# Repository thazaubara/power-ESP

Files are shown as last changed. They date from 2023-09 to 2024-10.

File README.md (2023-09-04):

# power-ESP
Simple ESP microcontroller that publishes power consumption to local MQTT. Includes 3D printed case. 

# MQTT NodeMCU

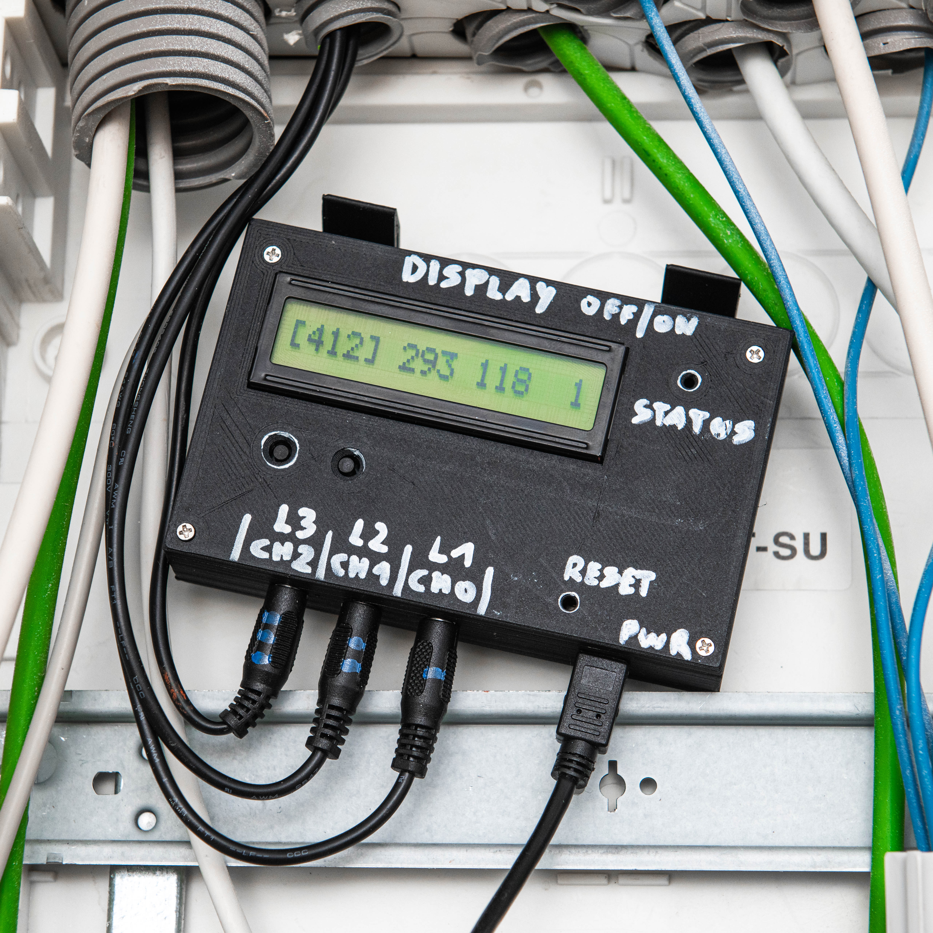
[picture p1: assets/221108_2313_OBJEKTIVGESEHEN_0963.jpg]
221108_2313_OBJEKTIVGESEHEN_0963


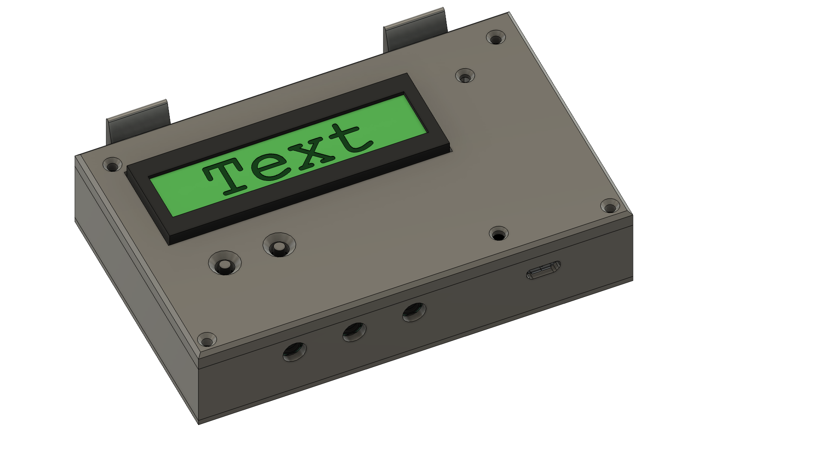
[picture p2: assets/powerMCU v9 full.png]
powerMCU v9 full


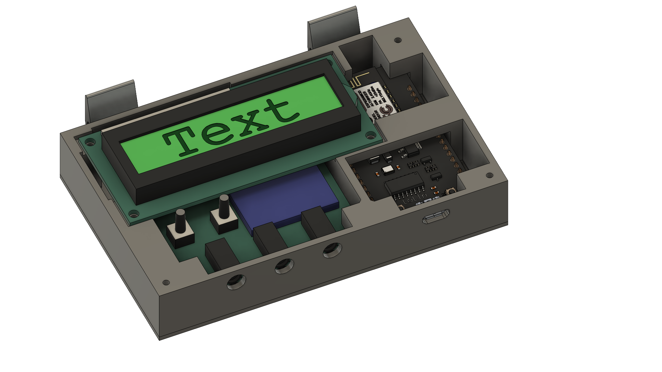
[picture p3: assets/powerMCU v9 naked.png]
powerMCU v9 naked


# NodeMCU

- Großes Board V3, 

- ESP8266, 

- CH340G USB-Serial

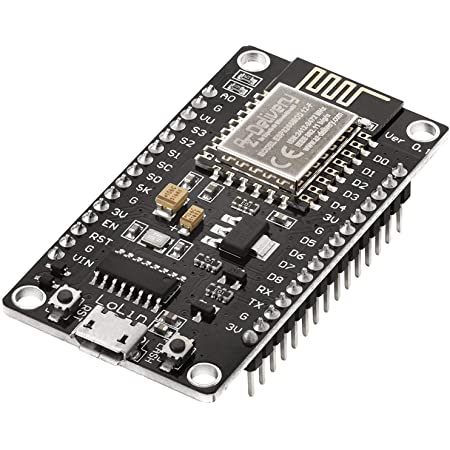
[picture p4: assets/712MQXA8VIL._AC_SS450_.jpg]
712MQXA8VIL._AC_SS450_
  

  NodeMCU Pinout Reference | Microcontroller Tutorials

# Software

- Arduino (Pro) IDE 2.0
- ESP Boards in Board Manager ([Tutorial](https://randomnerdtutorials.com/installing-esp8266-nodemcu-arduino-ide-2-0/))
- Braucht keine extra Treiber für USB-Serial @ M1 Macbook. Blinky läuft super.

# Projektspezfisch

- PubSubClient Library von Nick O'Leary ([Link](https://pubsubclient.knolleary.net)), in dem Library Manager von Arduino

# PowerMCU

## Features

- [ ] Display mit aktuellen Werten
- [ ] Cooles Case

## ToDo

Base Value reset (TARA)

Base Value im eeprom speichern

## Log

Vergleich [MCC118 RPI Hat](https://www.mccdaq.com/DAQ-HAT/MCC-118.aspx), [ADS1115](https://learn.adafruit.com/adafruit-4-channel-adc-breakouts/overview)
RPI Hat: 12 Bit, 8 CH, 100ks/s
ADS1115: 16 Bit, 4 CH, 860s/s

**[I2C Scanner](https://playground.arduino.cc/Main/sourceblock_1/index.txt?action=sourceblock&num=1) laufen gelassen**

Display: 0x27
ACD: 0x48

Display läuft, aber nur 8 zeichen von 16 (1 Zeile, mit I2C Board)
Vershiedene Modi:

- setup 8/2, cursor L0 L1
  nichts
- setup 16/1, cursor L0x16
  nur ersten 8 ch

Oke nach langem suchen und nichts finden, einfach display auf 5V (VUSB) angeschlossen, dann stimmt das
setup 16/2, L0x8, L1x8
ENDLICH

```c
LiquidCrystal_I2C lcd(0x27, 8, 2); // I2C address 0x27, 8 column and 2 rows
void printlcd(String s){
    lcd.setCursor(0,0);
    lcd.print(s.substring(0,8));
    lcd.setCursor(0,1);
    lcd.print(s.substring(8,16));
}
```

**Display funktioniert endlich.**

Upload Speed geiler machen. Wenn errors auftreten, hier ändern.

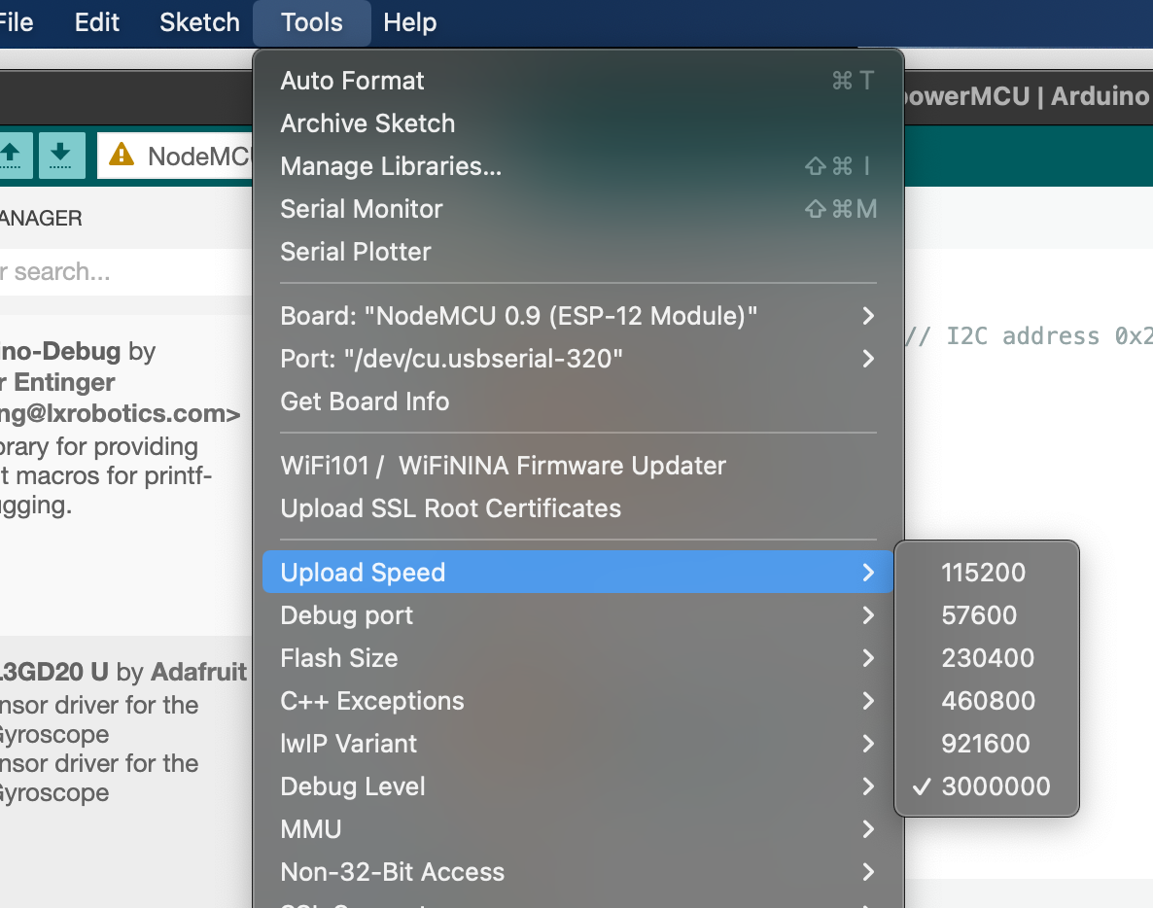
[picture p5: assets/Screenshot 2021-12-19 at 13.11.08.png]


ADC Sensor Basics mit der [Adafruit Library](https://learn.adafruit.com/adafruit-4-channel-adc-breakouts/arduino-code)

Berechnung der Spannung aus den Werten: einfache MAP Funktion

**Adafrut lib setzt ein delay** rein. limit 100 Samples pro sek. Andere Lib verwenden.

https://thecavepearlproject.org/2020/05/21/using-the-ads1115-in-continuous-mode-for-burst-sampling/

Lib geladen, installiert [Test sketch](https://github.com/terryjmyers/ADS1115-Lite/blob/master/examples/ADS1115_lite/ADS1115_lite.ino) rennt

Jetzt den Burst Mode: läuft auch

Test mit Klemme: Ikea 7W Lampe aufgebaut, kommt nichts an.
Stromzange sagt 0.05A wenns läuft. Auf 220V sind das 11 W

Das will ich auf der Klemme haben. Und am Oszi.

Alles rauscht extrem, ich bekomm kaum ein signal raus. ICh sollt einfach werte samplen über ne sekunde und dann berechnen, scheiß doch drauf. is keine Wissenschaft, sollte nur halbwegs passen.

Hier [einfaches Tutorial](https://www.poweruc.pl/blogs/news/non-invasive-sensor-yhdc-sct013-000-ct-used-with-arduino-sct-013) mit den selben sensoren. Trotzdem bessere lib nehmen statt adafruit.

Glühbirne reicht net. ich brauch mehr last. Habe den Föhn genommen

Glühbirne ~7W. Extrem viel rauschen. War ne LED, vielleicht liegts daran?

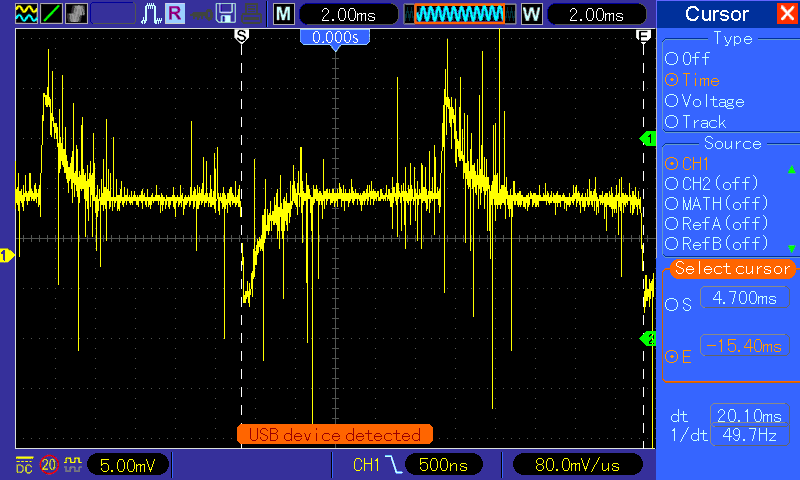
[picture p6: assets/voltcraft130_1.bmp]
voltcraft130_1


Föhn auf Vollgas ~2200W. Damit kann man arbeiten 😜 

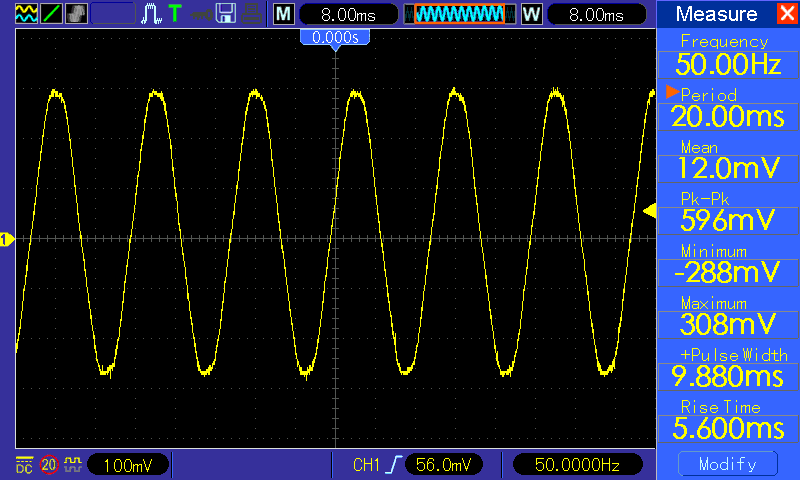
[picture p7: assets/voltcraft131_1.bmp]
voltcraft131_1


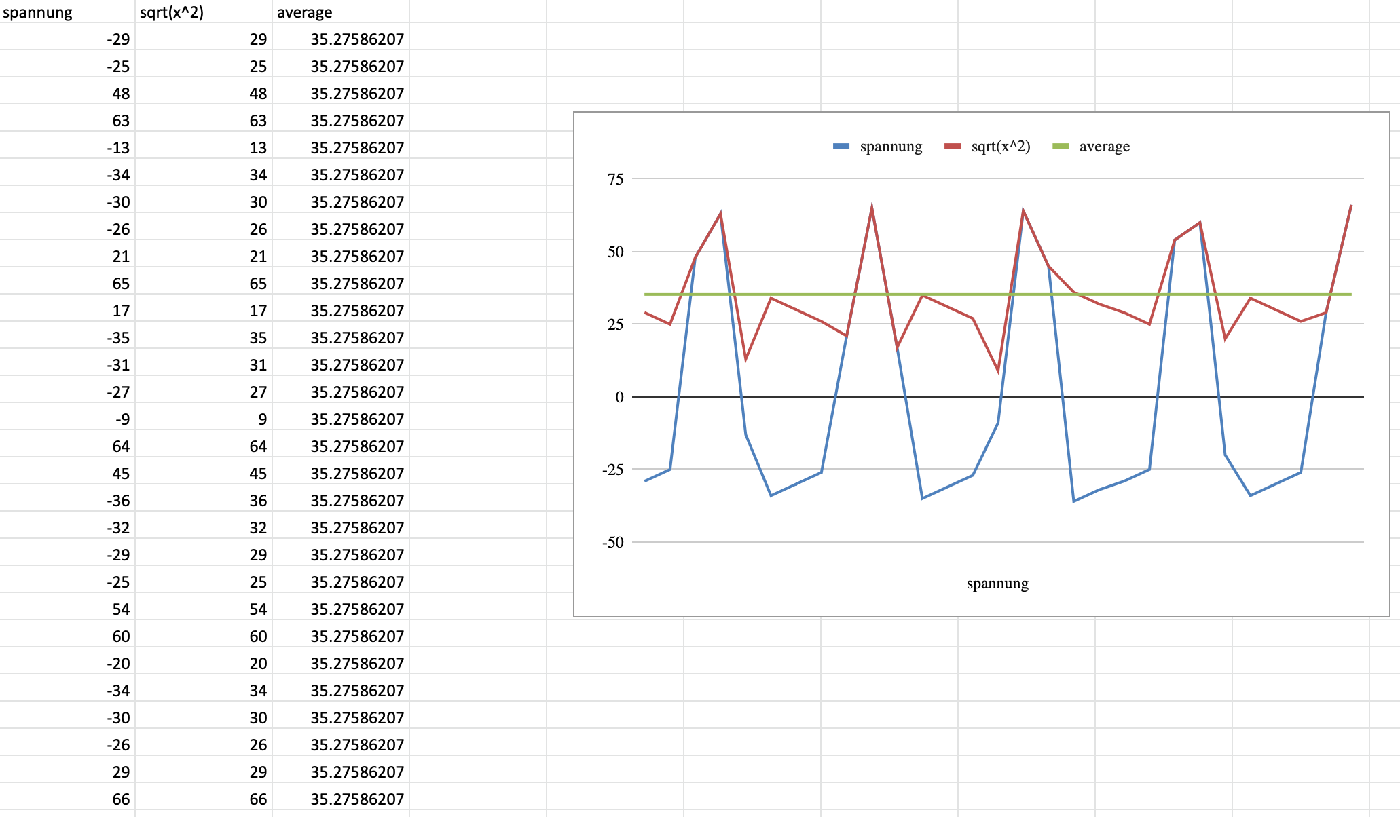
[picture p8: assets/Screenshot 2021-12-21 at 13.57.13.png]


1. in mv umrechnen
2. hochklappen (minus eintfernen)
3. average rechnen
4. amps berechnen
5. watt berechnen

Okay kalibrierung:

| | Stromzange | Multimeter, direkt | PowerMCU |
| --- | --- | --- | --- |
| Lampe | 0.048 (2A range) | 0.053 | 0.027 |
| Fühn Luft1, Heiz0 | 0.780 (2A range) | 0.806 | 0.704 |
| Föhn Luft2, Heiz0 | 1.364 | 1.394 | 1.195 |
| F L1, H1 | 2.28 | 2.353 | 2.079 |
| F L2, H1 | 4.13 | 4.25 | 3.660 |
| F L1, H2 | 4.08 | 4.21 | 3.627 |
| F L2, H2 | 7.96 | 8.16 | 5.054 |
| | | | |
| | | | |

Ich bekomm Multimeter und powerMCU einfach nicht auf die selben ergebnisse. Vielleicht weil die Kurven abgeschnitten sind und ich nicht genau weiß wo die Mitte der Kurve ist? Ist vielleicht die Berechnung von den Messgeräten auf einen schönen Sinus ausgelegt, den ich ja nicht hab?

Naja habs dabei belassen dass ich über das array Mittle und jeden wert berücksichtige. Das ist bei kleinen Lasten recht gut dabei, aber bei großen Lasten hab ich ggü dem Multimeter teilweise 50% abweichung. Ist aber der selbe rechenweg wie beim Raspberry, also lass ich das mal so.

# powerMCUv2 (TODO)

## Was soll es können?

- WiFi Verbindung (config auf SD Karte)
- Display für Statusanzeige
- Strommessung aller 3 Phasen
- Schickt Daten per MQTT
- Schickt Daten direkt an MySQL DB
- Offset austarieren
- Fallback Battery
- Wide Range DC Power In
- Log auf SD Card

## Hardware

- Microcontroller
  - ESP32
  - CH340G USB Serial Converter
  - Buck Converter (mini360)
- Micro SD Card Breakout
- Display
  - 1x20 Character Display
  - PCF8457 Display Driver
- ADS1115 ADC
- 3.5mm Klinke Input x3
- SCT013 20A/1V Strommmesser
- DIN Rail PSU

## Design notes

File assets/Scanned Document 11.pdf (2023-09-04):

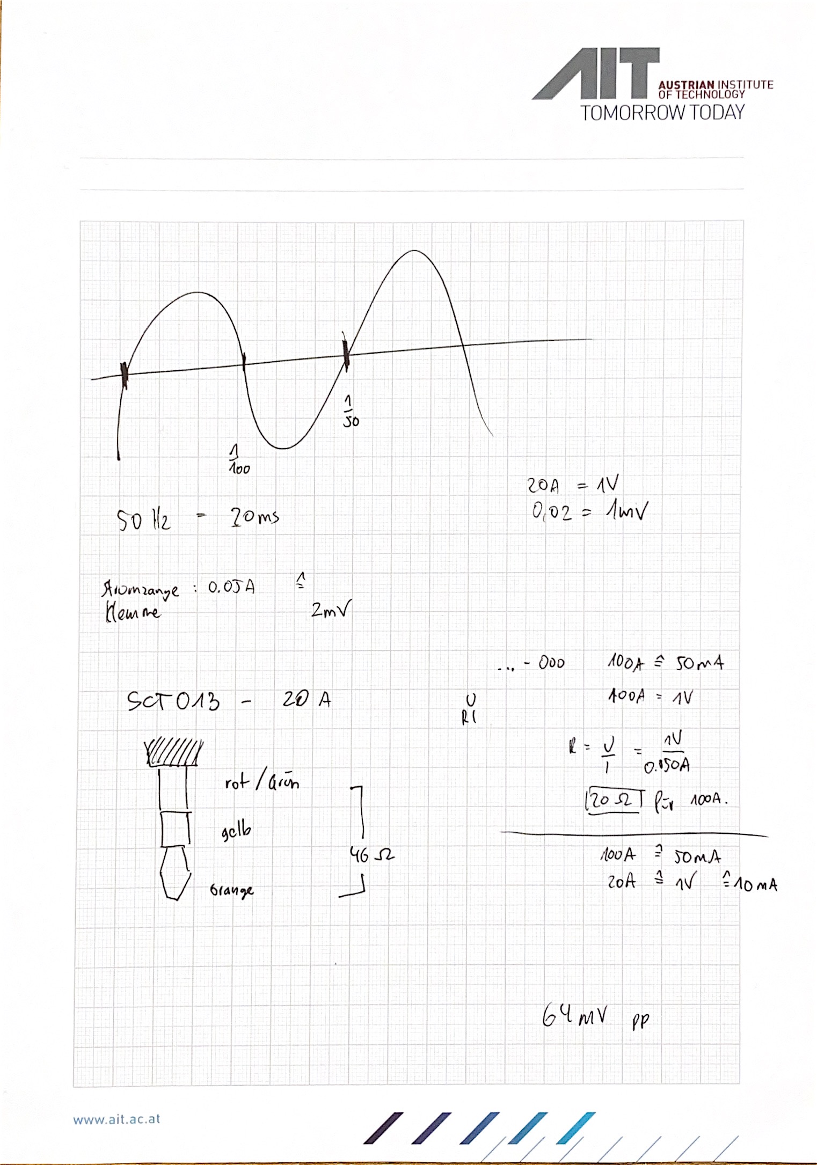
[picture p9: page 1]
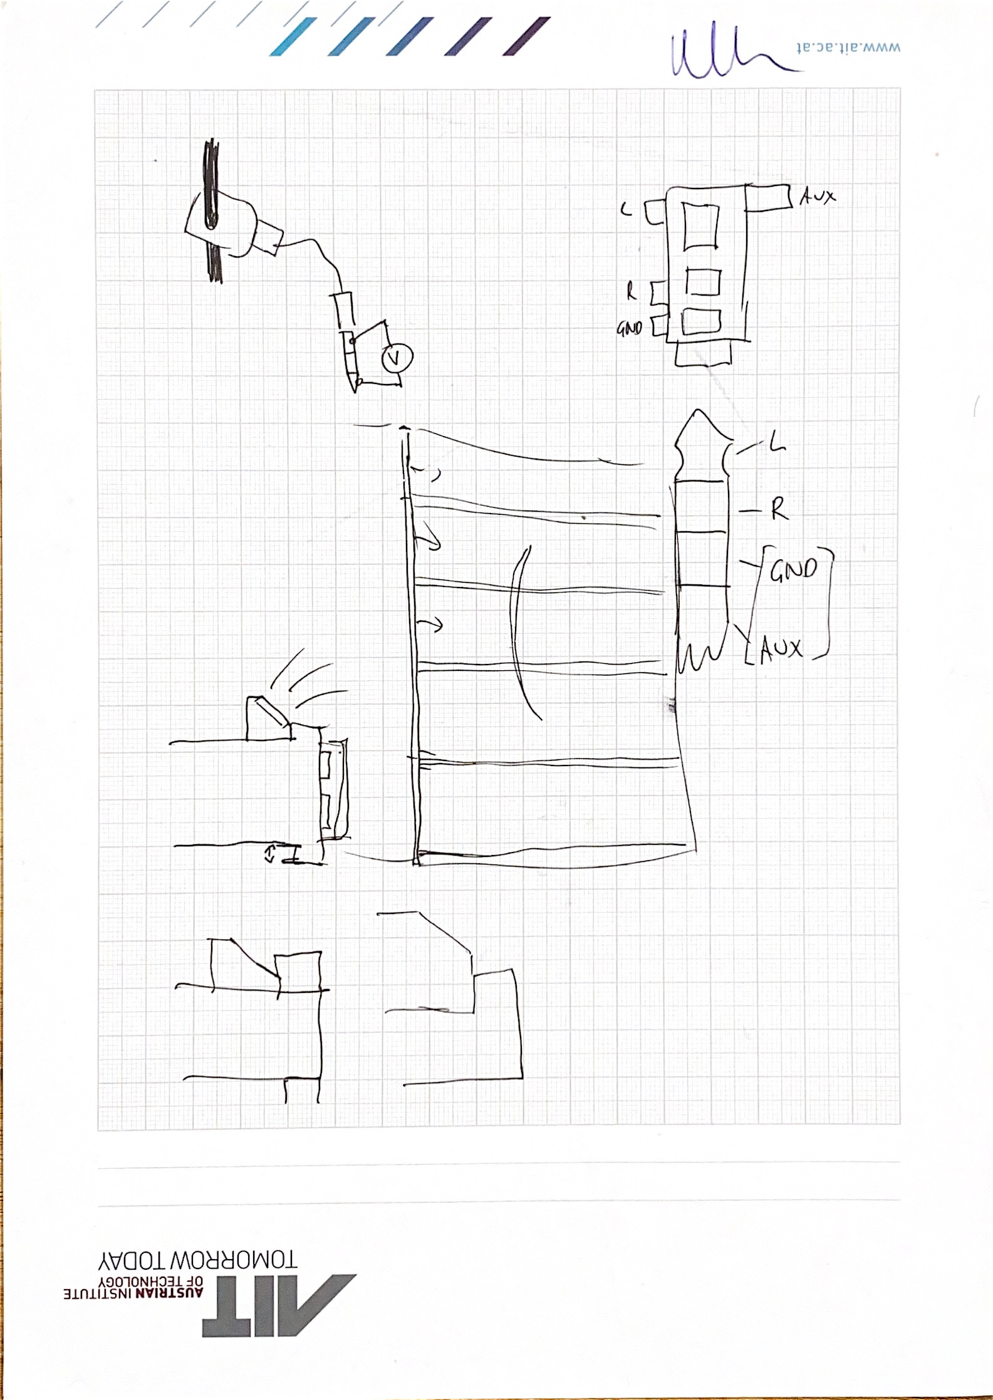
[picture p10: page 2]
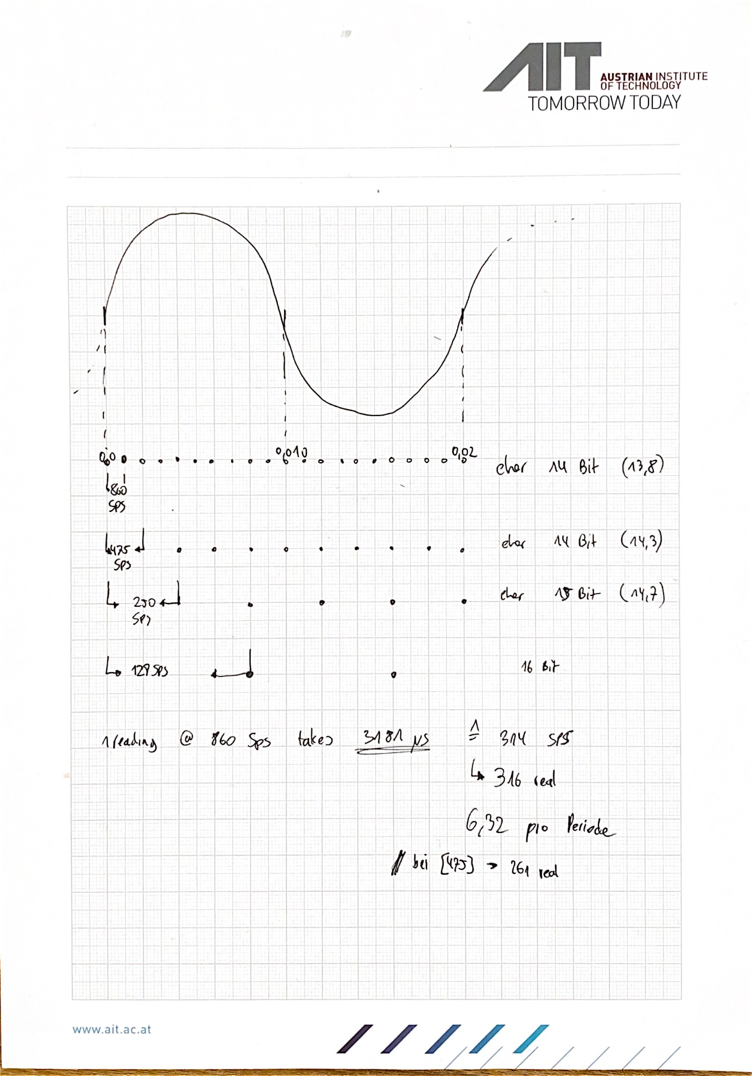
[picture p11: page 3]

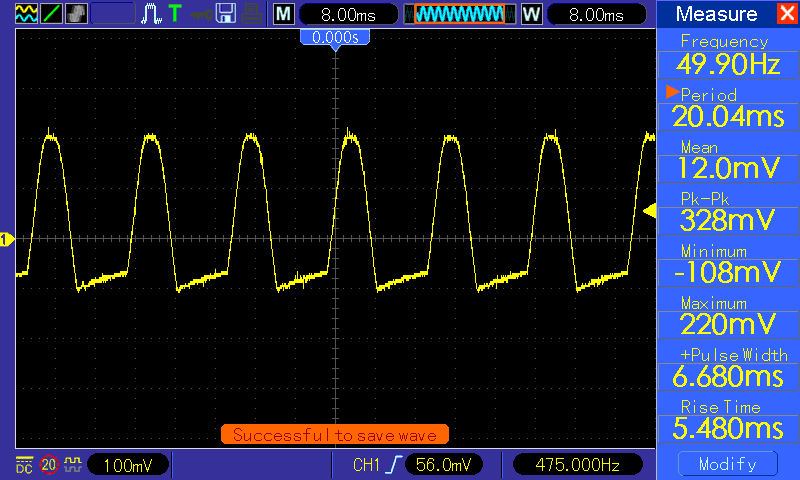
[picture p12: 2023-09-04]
assets/voltcraft131_2.bmp

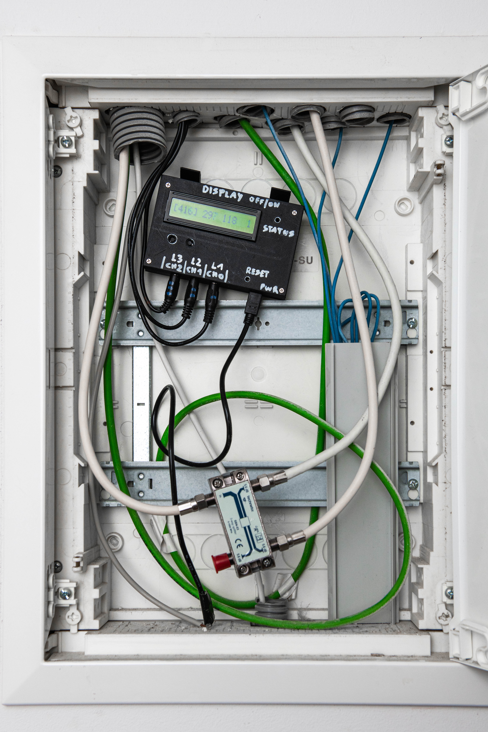
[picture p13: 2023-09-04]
assets/221108_2314_OBJEKTIVGESEHEN_0967.jpg

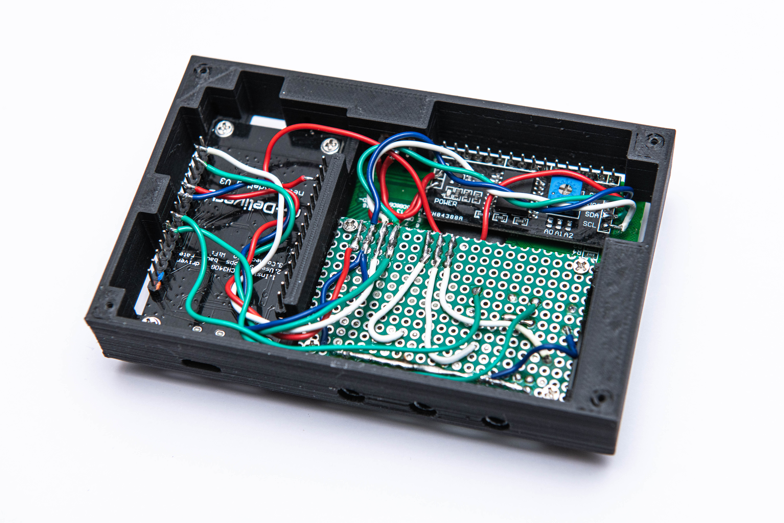
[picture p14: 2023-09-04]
assets/221108_2303_OBJEKTIVGESEHEN_0959.jpg

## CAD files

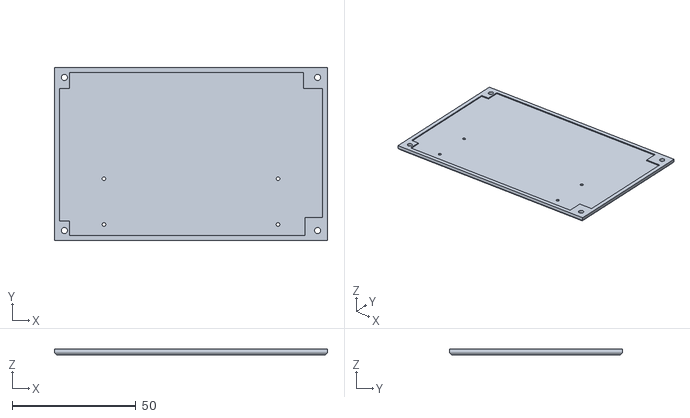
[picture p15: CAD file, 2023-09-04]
STL/powerMCU_bottom.stl
110.4 x 69.9 x 2.50

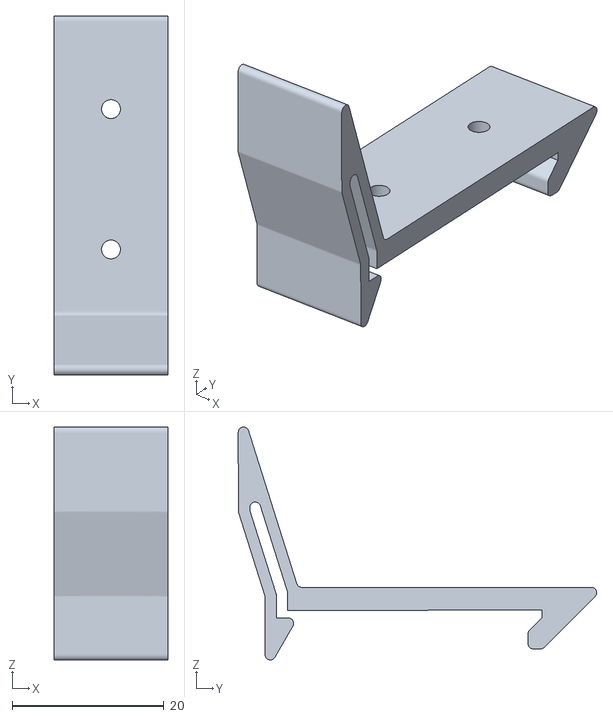
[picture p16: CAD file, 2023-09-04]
STL/Clamp(2).stl
15.0 x 47.3 x 30.7

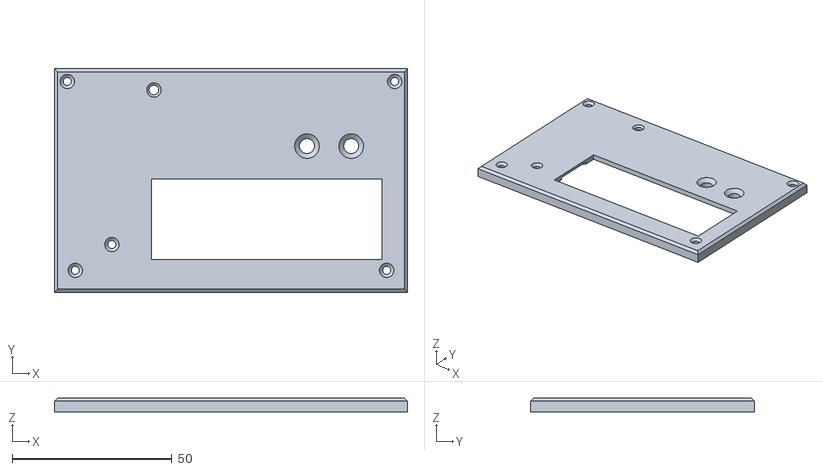
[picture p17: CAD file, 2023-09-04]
STL/powerMCU_deckel.stl
110.4 x 69.9 x 4.50

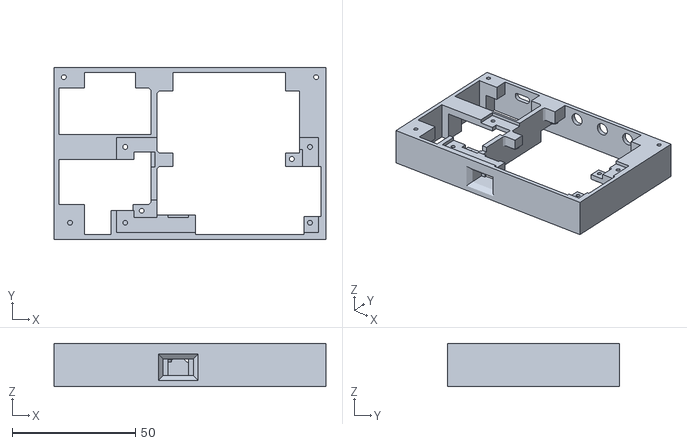
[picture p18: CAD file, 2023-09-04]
STL/powerMCU_case.stl
110.4 x 69.9 x 17.6

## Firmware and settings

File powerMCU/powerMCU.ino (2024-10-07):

#include <ESP8266WiFi.h>
#include <PubSubClient.h>
#include <LiquidCrystal_I2C.h>
#include <Wire.h>
#include <ADS1115_lite.h>

#define BTN_L D6
#define BTN_R D7

LiquidCrystal_I2C lcd(0x27, 8, 2); // I2C address 0x27, 16 column and 2 rows
ADS1115_lite adc(ADS1115_DEFAULT_ADDRESS);
WiFiClient espClient;
PubSubClient client(espClient);

const char* SSID = "";
const char* PSK = "";
const char* MQTT_BROKER = "";
const int PORT = 1883;
const int DELAY = 2000;
char msg[50];

float final_watt[3];
float final_amps[3];
float final_mv[3];

void printlcd(String s){
    lcd.clear();
    lcd.setCursor(0,0);
    lcd.print(s.substring(0,8));
    lcd.setCursor(0,1);
    lcd.print(s.substring(8,16));
}

void setup(){
  Serial.begin(115200);
  lcd.init(); // initialize the lcd
  lcd.backlight();
  if (!adc.testConnection()) {
    Serial.println("ADS1115 Connection failed"); //oh man...something is wrong
    printlcd("ADS1115 failed.");
    return;
  }

  pinMode(BTN_L, INPUT_PULLUP);
  pinMode(BTN_R, INPUT_PULLUP);

  pinMode(LED_BUILTIN, OUTPUT);     // Initialize the LED_BUILTIN pin as an output
  digitalWrite(LED_BUILTIN, LOW);
  printlcd("WiFi setup ...");
  setup_wifi();
  client.setServer(MQTT_BROKER, PORT);
  printlcd("ready ...");
}

void setup_wifi() {
	delay(10);
	Serial.println();
	Serial.print("Connecting to ");
	Serial.println(SSID);
	WiFi.begin(SSID, PSK);

	while (WiFi.status() != WL_CONNECTED) {
		delay(500);
		Serial.print(".");
	}

	Serial.println("");
	Serial.println("WiFi connected");
	Serial.println("IP address: ");
	Serial.println(WiFi.localIP());
}

void reconnect() {
	while (!client.connected()) {
		Serial.print("Reconnecting...");
		if (!client.connect("ESP8266_PowerESP")) {
			Serial.print("failed, rc=");
			Serial.print(client.state());
			Serial.println(" retrying in 5 seconds");
			delay(5000);
		}
	}
}

void readTrueWatt(int channel){
  int millis = 500;
  Serial.println("----- MEASURING CHANNEL " + String(channel) + " -----");
  Serial.println("True Watt. Average over all read Values");
  // SETUP
  switch (channel){
    case 0:
      adc.setMux(ADS1115_REG_CONFIG_MUX_SINGLE_0);
      break;
    case 1:
      adc.setMux(ADS1115_REG_CONFIG_MUX_SINGLE_1);
      break;
    case 2:
      adc.setMux(ADS1115_REG_CONFIG_MUX_SINGLE_2);
      break;

  }
  //adc.setMux(ADS1115_REG_CONFIG_MUX_SINGLE_0);          // welcher messmodus?
  adc.setSampleRate(ADS1115_REG_CONFIG_DR_860SPS);      // wie schnell?
  //adc.setSampleRate(ADS1115_REG_CONFIG_DR_475SPS);
  //adc.setSampleRate(ADS1115_REG_CONFIG_DR_128SPS);
  adc.setGain(ADS1115_REG_CONFIG_PGA_1_024V);           // welche range? +-1,024V
  int16_t ADS1115raw[500];

  // AQUIRE
  unsigned long startloop = micros();
  unsigned long endloop = micros() + millis * 1000;
  int samples = 0;
  while(micros() < endloop){
    adc.triggerConversion(); //Start a conversion.  This immediatly returns
    ADS1115raw[samples] = adc.getConversion(); //This polls the ADS1115 and wait for conversion to finish, THEN returns the value
    samples++;
  }

  double sum = 0;
  // TRUE RMS BERECHNUNG
  Serial.println("samples: " + String(samples) + ", time: " + String(millis/1000.0) + "s, " + String(samples/((millis/1000.0)*50)) + " samples/period");
  //Serial.println("first 10:");
  float max=0;
  float min=0;
  for (int j = 0; j < samples; j++){
    // 1. in mv umrechnen
    float mv = float(ADS1115raw[j])/32; // for 16 bit conversion. 
    if (mv > max){
      max = mv;
    }
    if (mv < min){
      min = mv;
    } 
    
    // 2. hochklappen
    if (mv < 0){
      mv = -mv; // leichter als mit sqrt
    }
    sum += mv;
  }

  if (min == 0 && max>100){
    final_amps[channel] = 0;
    final_watt[channel] = 0;
    final_mv[channel] = 0;
    return;
  }

  Serial.println("vpp: " + String(max-min,3) + "mv, min: " + String(min,3) + "mV, max: " + String(max, 3) + "mV");
  // 3. AVERAGE RECHNEN
  float average = sum/float(samples);
  Serial.println("average: " + String(average, 3) + "mV " + "sum: " + String(sum));

  // 4. AMPS BERECHNEN
  float amps = average * 0.020;
  Serial.println("amps: " + String(amps, 3) + "A");

  // 5. WATT RMS BERECHNEN
  float watt = amps * 236;
  Serial.println("watt: " + String(watt, 3) + "W");

  // PRINT & STORE VALUES
  final_amps[channel] = amps;
  final_watt[channel] = watt;
  final_mv[channel] = average;
}

void readForTime(){
  Serial.println("----- MEASURING -----");
  // SETUP
  adc.setMux(ADS1115_REG_CONFIG_MUX_SINGLE_0);          // welcher messmodus?
  adc.setSampleRate(ADS1115_REG_CONFIG_DR_860SPS);      // wie schnell?
  //adc.setSampleRate(ADS1115_REG_CONFIG_DR_475SPS);
  adc.setGain(ADS1115_REG_CONFIG_PGA_1_024V);           // welche range? +-1,024V
  int16_t ADS1115raw[500];

  // AQUIRE
  unsigned long startloop = micros();
  unsigned long endloop = micros() + 1000000;
  int samples = 0;
  while(micros() < endloop){
    adc.triggerConversion(); //Start a conversion.  This immediatly returns
    ADS1115raw[samples] = adc.getConversion(); //This polls the ADS1115 and wait for conversion to finish, THEN returns the value
    samples++;
  }

  double sum = 0;
  // TRUE RMS BERECHNUNG
  Serial.println("samples: " + String(samples));
  Serial.println("first 10:");
  float max=0;
  float min=0;
  for (int j = 0; j < samples; j++){
    // 1. in mv umrechnen
    float mv = float(ADS1115raw[j])/32; // for 16 bit conversion. 
    if (mv > max){
      max = mv;
    }
    if (mv < min){
      min = mv;
    } 
    if (j < 10){
      Serial.println("__" + String(ADS1115raw[j]) + " -> " + String(mv,2) + "mV");
    }
    
    //Serial.println(String(mv));
    // 2. hochklappen
    if (mv < 0){
      mv = -mv; // leichter als mit sqrt
    }
    //Serial.println(String(mv));
    sum += mv;
  }
  Serial.println("min: " + String(min,3) + "mV, max:" + String(max, 3) + "mV");
  // 3. AVERAGE RECHNEN
  Serial.println("sum: " + String(sum));
  float average = sum/float(samples);
  Serial.println("average: " + String(average, 3) + "mV");

  // 4. AMPS BERECHNEN
  float amps = average * 0.020;
  Serial.println("amps: " + String(amps, 3) + "A");

  // 5. WATT RMS BERECHNEN
  float watt = amps * 236;
  Serial.println("watt: " + String(watt, 3) + "W");

  // 6. RMS minmax
  float vrms = ((max-min) / 2) * 0.707;
  float amprms = vrms * 0.020;
  float wattrms = amprms *236;
  Serial.println("simple_rms, amps: " + String(amprms, 3) + "A");
  Serial.println("simple_watt: " + String(wattrms, 3) + "W");

  printlcd(String(wattrms,2) + "W " + String(amprms,3) + "A");

}

void singleShot(){
  adc.setMux(ADS1115_REG_CONFIG_MUX_SINGLE_0);          // welcher messmodus?
  adc.setSampleRate(ADS1115_REG_CONFIG_DR_860SPS);      // wie schnell?
  adc.setGain(ADS1115_REG_CONFIG_PGA_1_024V);           // welche range? +-1,024V
  
  int16_t value;
  unsigned long start;
  unsigned long end ;

  start = micros(); //Record a start time for demonstration
  adc.triggerConversion(); //Start a conversion.  This immediatly returns
  value = adc.getConversion(); //This polls the ADS1115 and wait for conversion to finish, THEN returns the value
  end = micros();
  printlcd(String(value, DEC) + ": " + String(end-start, DEC) + "us");
}

void publish(String topic, String message){
  char t[50];
  char m[50];
  message.toCharArray(m,50);
  topic.toCharArray(t,50);
  client.publish(t,m);
}

void sendAlive(){
  digitalWrite(LED_BUILTIN, LOW);

  // SEND REAL STUFF
  snprintf (msg, 50, "Alive since %ld milliseconds", millis());
  //Serial.print("Publish message: ");
  Serial.println(msg);
  client.publish("homesens/ESP32/power/message", msg);

  // SEND IP ADDRESS
  char bufIp [20];
  IPAddress ipaddr = WiFi.localIP();
  sprintf(bufIp, "%d.%d.%d.%d", ipaddr[0], ipaddr[1], ipaddr[2], ipaddr[3]);
  client.publish("homesens/ESP32/power/ip", bufIp);

  // SEND MAC ADDRESS
  String mac = String(WiFi.macAddress());
  char bufMac [20];
  mac.toCharArray(bufMac, 20);
  client.publish("homesens/ESP32/power/mac", bufMac);

  digitalWrite(LED_BUILTIN, HIGH);
}

void loop()
{
  if (!client.connected()) {
    digitalWrite(LED_BUILTIN, LOW);
    printlcd("reconnecting ...");
		reconnect();
	}

  // MQTT STUFF
  client.loop(); 
  sendAlive();

  readTrueWatt(0);
  digitalWrite(LED_BUILTIN, LOW);
  publish("homesens/ESP32/power/sum_watt", String(final_watt[0] + final_watt[1] + final_watt[2],0));
  publish("homesens/ESP32/power/L1_watt", String(final_watt[0],0));
  publish("homesens/ESP32/power/L1_amp", String(final_amps[0],2));
  publish("homesens/ESP32/power/L1_sensor_mV", String(final_mv[0],3));
  printlcd("[" + String(final_watt[0] + final_watt[1] + final_watt[2],0) + "] " + String(final_watt[2],0) + " " + String(final_watt[1],0) + " " + String(final_watt[0],0));
  digitalWrite(LED_BUILTIN, HIGH);

  readTrueWatt(1);
  digitalWrite(LED_BUILTIN, LOW);
  publish("homesens/ESP32/power/sum_watt", String(final_watt[0] + final_watt[1] + final_watt[2],0));
  publish("homesens/ESP32/power/L2_watt", String(final_watt[1],0));
  publish("homesens/ESP32/power/L2_amp", String(final_amps[1],2));
  publish("homesens/ESP32/power/L2_sensor_mV", String(final_mv[1],3));
  printlcd("[" + String(final_watt[0] + final_watt[1] + final_watt[2],0) + "] " + String(final_watt[2],0) + " " + String(final_watt[1],0) + " " + String(final_watt[0],0));
  digitalWrite(LED_BUILTIN, HIGH);
  
  readTrueWatt(2);
  digitalWrite(LED_BUILTIN, LOW);
  publish("homesens/ESP32/power/sum_watt", String(final_watt[0] + final_watt[1] + final_watt[2],0));
  publish("homesens/ESP32/power/L3_watt", String(final_watt[2],0));
  publish("homesens/ESP32/power/L3_amp", String(final_amps[2],2));
  publish("homesens/ESP32/power/L3_sensor_mV", String(final_mv[2],3));
  printlcd("[" + String(final_watt[0] + final_watt[1] + final_watt[2],0) + "] " + String(final_watt[2],0) + " " + String(final_watt[1],0) + " " + String(final_watt[0],0));
  digitalWrite(LED_BUILTIN, HIGH);

  // FINISH
}

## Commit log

2023-09-04 uploaded project files
    [Clamp(2).stl, powerMCU_bottom.stl, powerMCU_case.stl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]
2023-09-04 switched image syntax to html
2024-03-10 arduino compatible folder structure
